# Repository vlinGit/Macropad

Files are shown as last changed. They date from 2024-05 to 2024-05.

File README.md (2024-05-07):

<h1 align="center"> Macropad </h1>

## Table of Contents
* [Introduction](#introduction)
* [Macropad](#macropad)
    * [Schematic](#schematic)
    * [PCB](#pcb)
    * [Parts](#parts)
* [Firmware](#firmware)
    * [Default mode](#default-mode)
    * [Function mode](#function-mode)
* [Future plans](#future-plans)

<hr>

## Introduction

Greetings, It seems you've stubbled upon my macropad project :)!
Utilizing everything provided from this repo (with a few exceptions) you should be able to make this simple 4x4 macropad using a Pi Pico:

<p align="center">
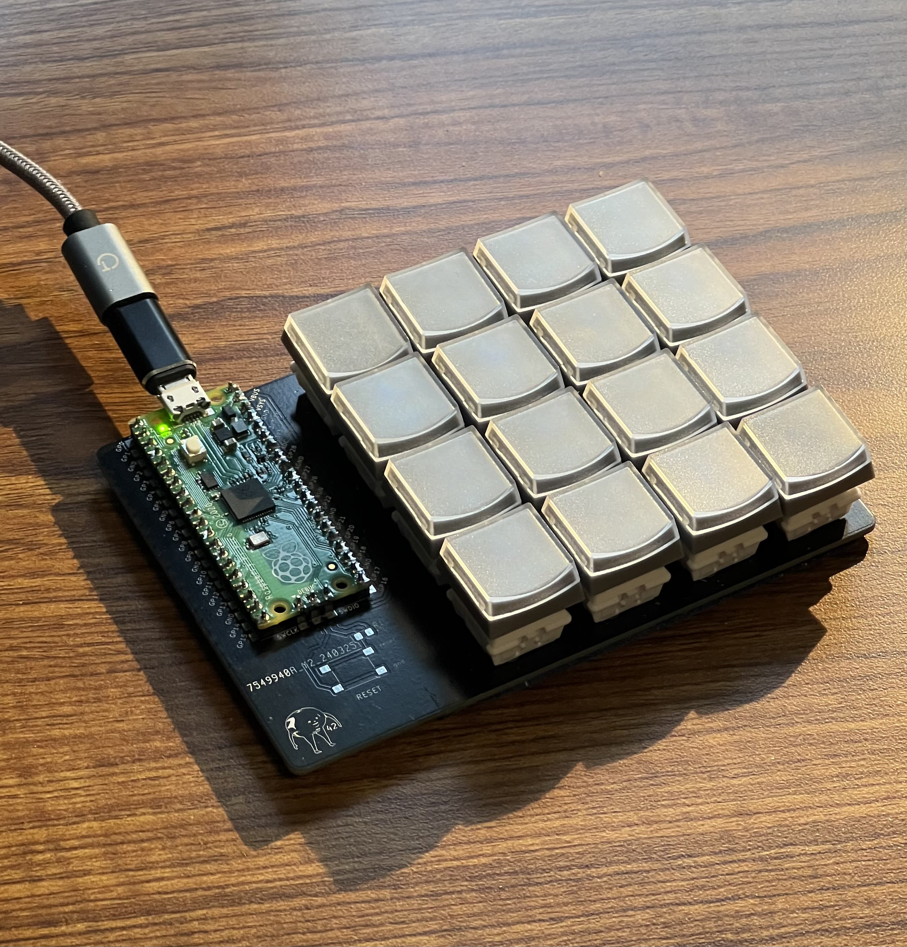
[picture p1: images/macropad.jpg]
    
</p>

Now I must set some ground rules and mentions those exceptions from the previous text. 
This repo assumes you have knowledge of:

* [Python](https://www.python.org/)
* [Kicad](https://www.kicad.org/)
* [CircuitPython](https://circuitpython.org/) - This should be installed on your Pi Pico

The next two sections will discuss what the two folders, Macropad and Firmware, in this project do.
<hr>

## Macropad

All the project files (schematic, pcb, and fingerprints) should be in this folder. When opening this within Kicad, you will most likely need to reassign the location of the fingerprints.

##### Schematic:
<p align="center">
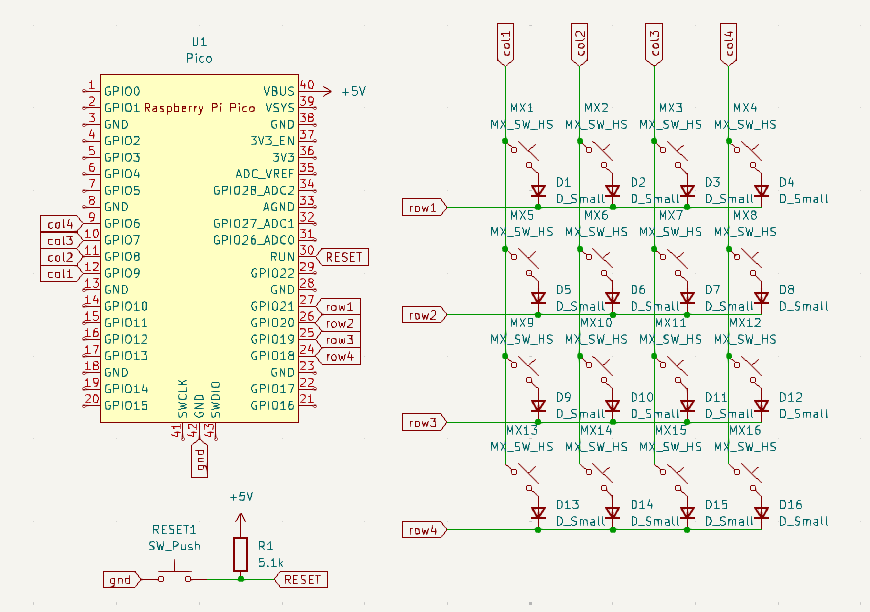
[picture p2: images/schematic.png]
    
</p>

##### PCB:
<p align="center">
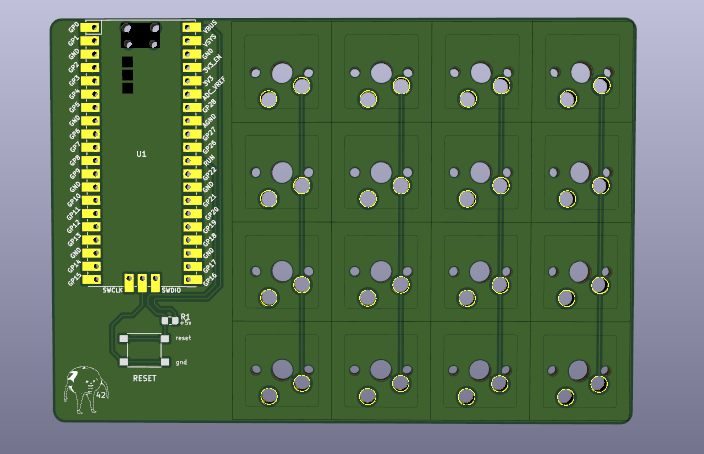
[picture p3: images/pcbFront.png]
    
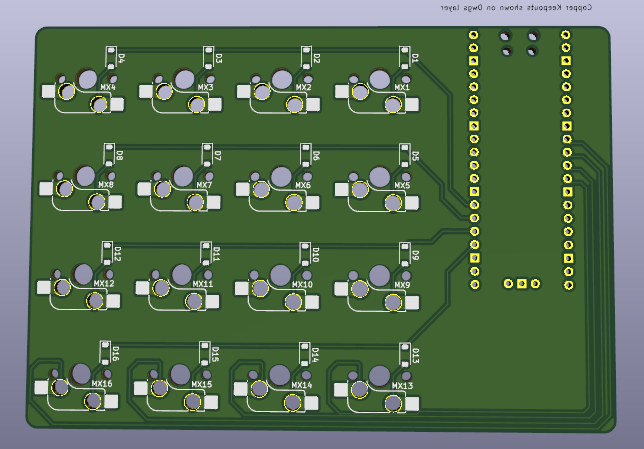
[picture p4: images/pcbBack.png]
    
</p>

##### Parts:
* 16 Kahlil hotswap sockets
* 1 Raspberry Pi Pico
* 16 SMD Diodes
* Header pins for the pico (optional)
* Micro usb wire
* Soldering kit

Here's a [spreadsheet](https://docs.google.com/spreadsheets/d/1NUBolih80QTXxrNlfvGj-lknc-THMJnu64dy0pHb7lM/edit?usp=sharing) containing all the items I used. This spreadsheet doesn't include headers, switches, and keys as I already had these lying around.

<i><b>Sidenote</b>, I left a place for a reset button for convinence, however, this proved to be the complete opposite. The small button got in the way more often than not so the final build doesn't include it. </i>

<hr>

## Firmware

You will find a <b>lib</b> folder as well as a <b>code.py</b> file in here. The <b>lib</b> folder contains the necessary adafruit library needed for the python file <b>code.py</b> which contains the actual firmware code. These files should be dragged into your Pi Pico after you've installed CircuitPython.

The macropad is designed in a 4x4 matrix with the following pins:

* Rows: GP21, GP20, GP19, GP18
* Columns: GP6, GP7, GP8, GP9

The current python file provides you with two modes:
1. [Default mode](#default-mode) - for media controls
2. [Function mode](#function-mode) - for general purpose binds using F13-F21 keys, mainly for binding macros in software (blender, kritia, etc.)

The modes will be presented in tables, each cell being a key. Every cell labeled <i>null</i> means the key is unassigned. Within the actual code this is represented with a -1.

##### Default Mode:

<table>
    <tr>
        <td>VOLUME DECREMENT</td>
        <td>VOLUME INCREMENT</td>
        <td>MUTE VOLUME</td>
        <td>CHANGE MODE</td>
    </tr>
    <tr>
        <td>PREVIOUS TRACK</td>
        <td>PLAY/PAUSE MEDIA</td>
        <td>NEXT TRACK</td>
        <td><i>null</i></td>
    </tr>
    <tr>
        <td><i>null</i></td>
        <td><i>null</i></td>
        <td><i>null</i></td>
        <td><i>null</i></td>
    </tr>
    <tr>
        <td><i>null</i></td>
        <td><i>null</i></td>
        <td><i>null</i></td>
        <td><i>null</i></td>
    </tr>
</table>

##### Function Mode:

<table>
    <tr>
        <td>LEFT SHIFT</td>
        <td>F14</td>
        <td>F15</td>
        <td>CHANGE MODE</td>
    </tr>
    <tr>
        <td>F13</td>
        <td>F17</td>
        <td>F18</td>
        <td>F19</td>
    </tr>
    <tr>
        <td>F16</td>
        <td>F21</td>
        <td>F22</td>
        <td>F23</td>
    </tr>
    <tr>
        <td>LEFT CONTROL</td>
        <td>F20</td>
        <td><i>null</i></td>
        <td>SPACE</td>
    </tr>
</table>

<hr>

## Future plans

So, whats planned for the future? I've been using this macropad for a couple days now and here's the following things I plan on implementing soon:

1. <b>Proper case</b> - I've created the model, but now just need to get a 3D printer and do some troubleshooting
2. <b>Rotary Encoders</b> - Will be great for volume control and zooming in
3. <b>Standalone LED + Mode button</b> - Just for mode switching
4. <b>IR Sensors</b> - Really looking forward to this one! Plan on adding AC and table height controls using this.

As to what I will remove:
1. <b>The reset button</b> - Honestly made it less comfortable to use
2. <b>Micro usb</b>- Looking to replace this with a USB-C port

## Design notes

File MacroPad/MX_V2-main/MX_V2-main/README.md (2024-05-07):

Cover Image 
# MX_V2
Second generation KiCad Libraries of keyboard switch footprints  

<!-- ![Footprint Image](https://raw.githubusercontent.com/ai03-2725/MX_Alps_Hybrid.pretty/master/Screenshots/Footprint.png)   -->
Designed as the successor to [the original MX_Alps_Hybrid library](https://github.com/ai03-2725/MX_Alps_Hybrid), with significantly improved sustainability and modularity.  
Unlike the original monolithic library, this new library separates switch types and components (LEDs and similar) as much as possible for simpler schematics, and is intended to be used with default KiCad symbols (such as `SW_Push`).

## Features
* Designed from scratch using official datasheets and accurate measurements
* Almost every switch size in existence
* Topside soldermask to prevent solder overflow and improve appearance
* Various keysizes for all occasions
* Keysizes are generated via the script generate.py from a single footprint, making the library extensible and maintainable
* Intended for production use

## Included Footprint Libraries
* **MX_Solderable.pretty** - For Cherry MX type switches via soldered pads.
* **MX_Hotswap.pretty** - For Cherry MX type switches via hotswap sockets.
* **Alps_Solderable.pretty** - For alps SKCM/SKCL, SKBM/SKBL, and clones with same pin structure.  
* **MX_Alps_Hybrid.pretty** - Hybrid MX/Alps compatible solderable footprints.
* **Gateron_KS33_Solderable.pretty** - For Gateron Low Profile (V1.0 or V2.0, KS-27 or KS-33) switches via soldered pads.
* **Gateron_KS33_Hotswap.pretty** - For Gateron Low Profile (V1.0 or V2.0, KS-27 or KS-33) switches via hotswap sockets.
* **Switch_Misc.pretty** - Misc footprints such as LED footprints.
* Template.pretty - The template footprints that the script uses to generate footprints automatically. Do not use in production.

### Footprint Variants
* -ReversedStabilizers - Reversed stabilizer direction (north- vs south-facing).

### Misc Parts Variants
* -LED - LEDs that align to each switch footprint. Prefix denotes which type of switch they are applicable to.
* -Reversed - Inverts pin 1 order (left vs right square pad).
* -PolarityMarked - Marks pin 1 with a + icon to denote positive polarity (only useful if pin 1 is the higher voltage).

### 3D Model Troubleshooting
Due to limitations in KiCad, there is no particularly elegant way to handle 3D models for non-plugin third-party libraries.  
If you have issues seeing the 3D models or exporting them in STEP files, copy the contents of the `3D` directory to your project's root folder alongside the kicad project files.  

## Contributing
Verbal "Please create this" will usually be declined due to lack of time available for maintenance.  
Massive overhauls that completely change the structure of the library or code will be declined if made without prior discussion.  
When creating PRs, please verify the following:  
* A template footprint is created in Template.pretty if creating a new family type, with the file modified to have "Template" for all script-replaced unit/variant text.  
* Code modifications are done in a sane, clean manner.
* Footprints are made from datasheets, empirical testing, and/or reasonable expectations.
* All footprints in a switch library (i.e. not a one-off LED footprint or similar) are generated from the script and are not manually modified.
* Once everything is tested functional, add the line to generate the library folder for the footprint family automatically in `Generator/generate-all.sh`.

### Todo
* Script todos
  * Make ISO outlines scale by unit width/height parameters
  * Add stabilizer clearance keepout zones for Gateron KS33 footprints
* Ease of use
  * Add screenshots of 3D model, footprint

## Credits
* All authors and contributors to the [original V1 switch library](https://github.com/ai03-2725/MX_Alps_Hybrid)

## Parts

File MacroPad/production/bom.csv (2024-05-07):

Designator | Footprint | Quantity | Value | LCSC Part #
D1, D10, D11, D12, D13, D14, D15, D16, D2, D3, D4, D5, D6, D7, D8, D9 | D_SOD-123 | 16 | D_Small
MX1, MX10, MX11, MX12, MX13, MX14, MX15, MX16, MX2, MX3, MX4, MX5, MX6, MX7, MX8, MX9 | SW_MX_HS_CPG151101S11_1u | 16 | MX_SW_HS
R1 | 0805 | 1 | 5.1k
RESET | SW_SPST_PTS645 | 1 | SW_Push
U1 | RPi_Pico_SMD_TH | 1 | Pico

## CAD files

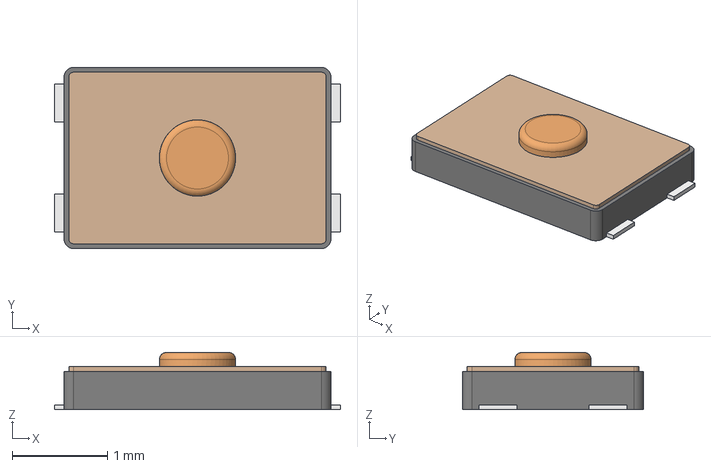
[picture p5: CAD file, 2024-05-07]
MacroPad/marbastlib-main/marbastlib-main/3dmodels/SW_T1A2QR.step
3.00 x 1.90 x 0.6 mm

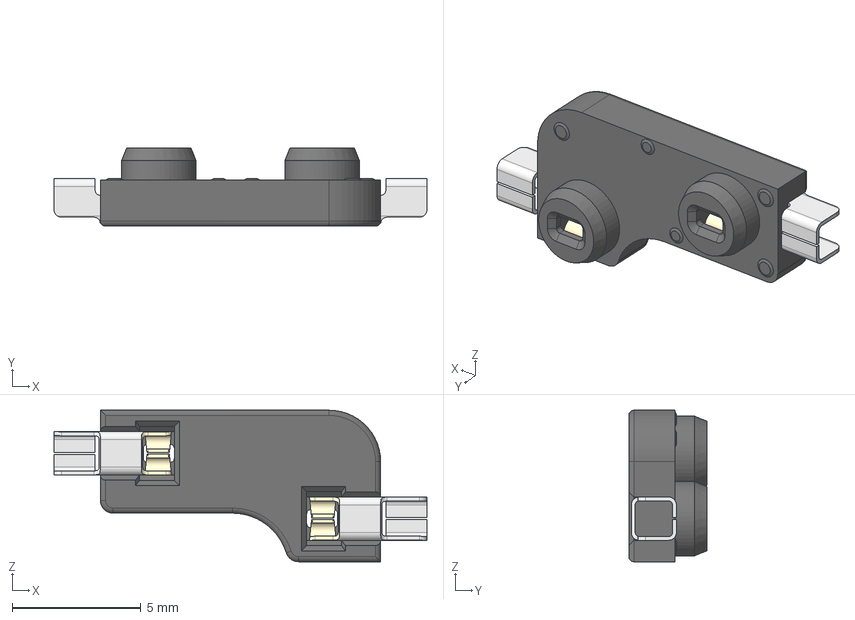
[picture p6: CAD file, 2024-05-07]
MacroPad/MX_V2-main/MX_V2-main/3D/MX-Hotswap-Socket.step
14.5 x 3.05 x 5.89 mm

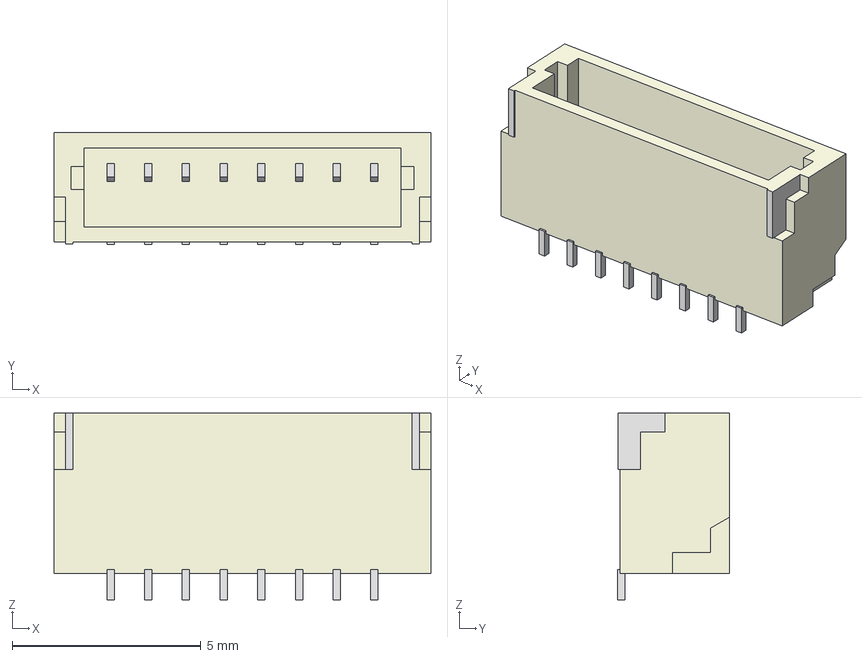
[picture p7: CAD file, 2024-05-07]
MacroPad/marbastlib-main/marbastlib-main/3dmodels/CON_SM08B-SRSS-TB.step
10.0 x 2.96 x 4.95 mm

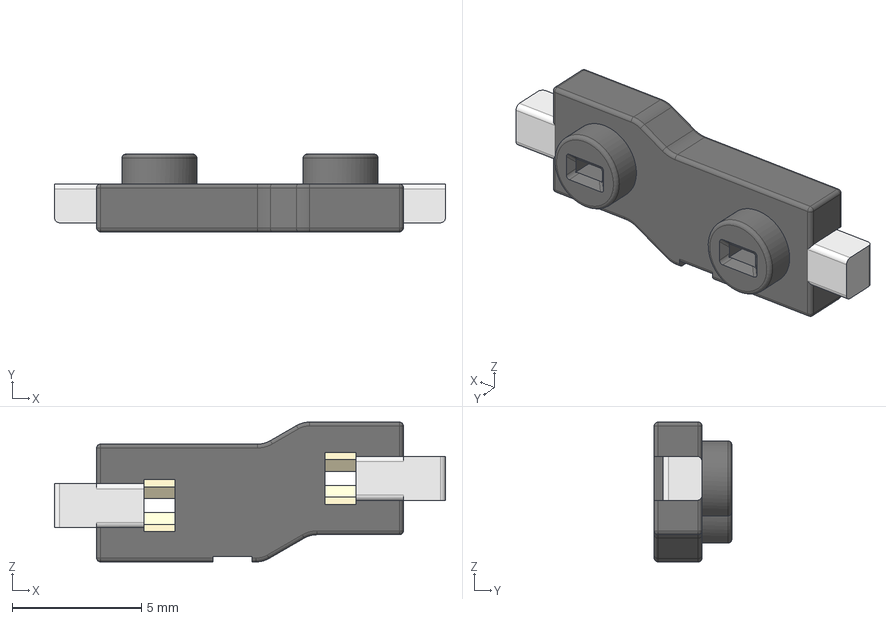
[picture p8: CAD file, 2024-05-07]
MacroPad/MX_V2-main/MX_V2-main/3D/Gateron-KS33-Socket.step
15.1 x 3.00 x 5.40 mm

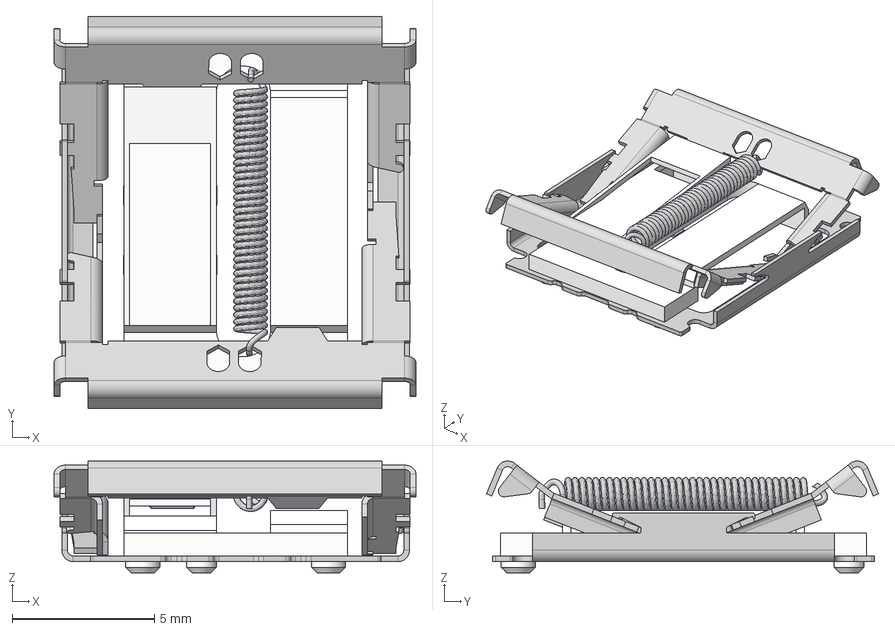
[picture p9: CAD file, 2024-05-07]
MacroPad/marbastlib-main/marbastlib-main/3dmodels/SW_MX6C-K3NB.step
12.7 x 13.8 x 3.93 mm

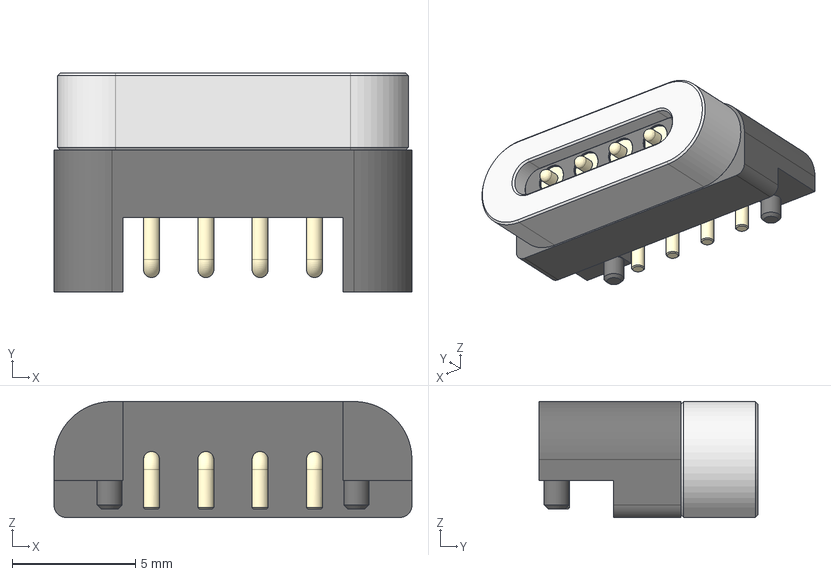
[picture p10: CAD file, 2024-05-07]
MacroPad/marbastlib-main/marbastlib-main/3dmodels/CON_HytePro_M411P_Receptacle_1x04.step
14.5 x 8.85 x 4.70 mm
Magnetic Connector Female - MiddlePart
Magnetic Connector Female-tip_Standard
Magnetic Connector Female v2 - MountingPart

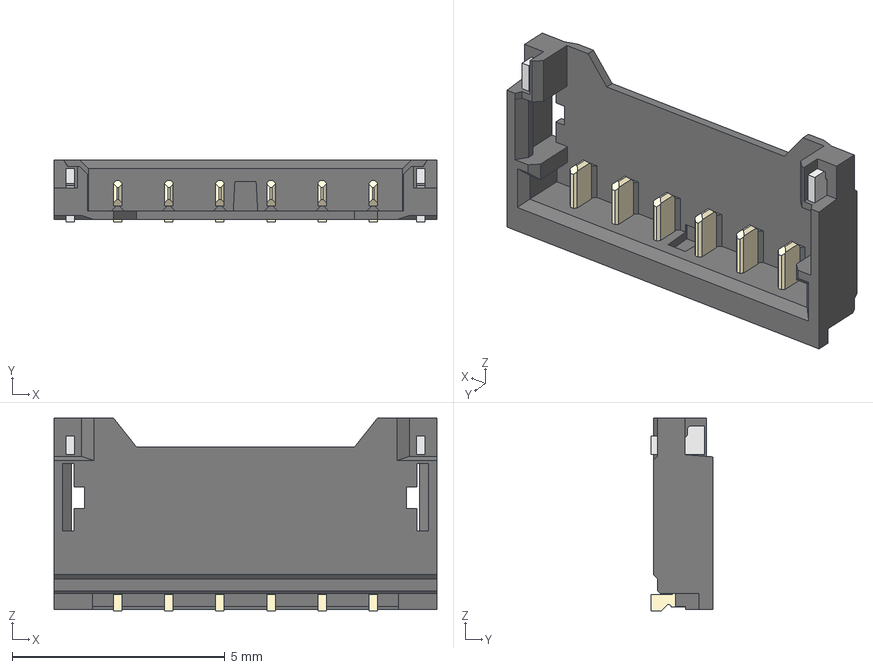
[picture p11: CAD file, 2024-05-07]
MacroPad/marbastlib-main/marbastlib-main/3dmodels/CON_781715006.step
9.00 x 1.45 x 4.53 mm

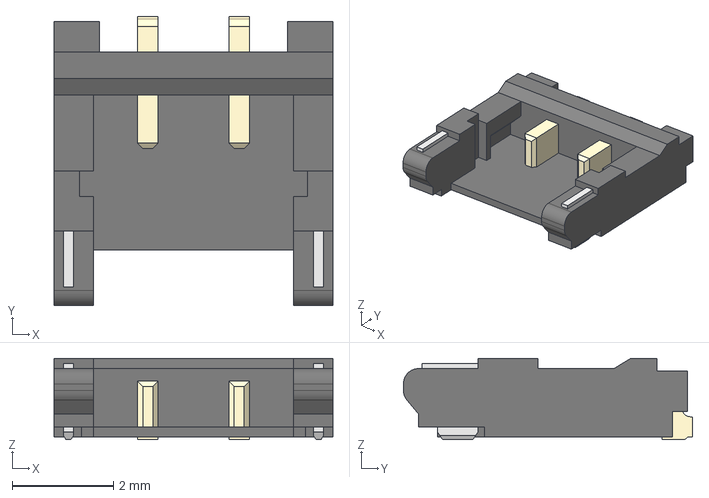
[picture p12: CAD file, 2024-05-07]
MacroPad/marbastlib-main/marbastlib-main/3dmodels/CON_2082940020.step
5.50 x 5.70 x 1.60 mm

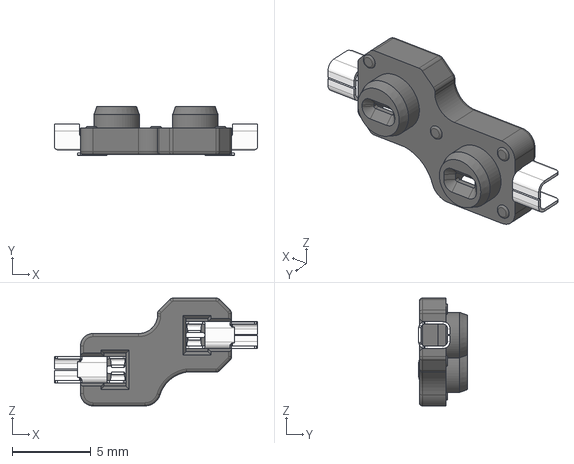
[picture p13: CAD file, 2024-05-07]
MacroPad/marbastlib-main/marbastlib-main/3dmodels/HS_CPG135001S30_Choc.step
12.9 x 3.09 x 6.85 mm
pin x 2
socket

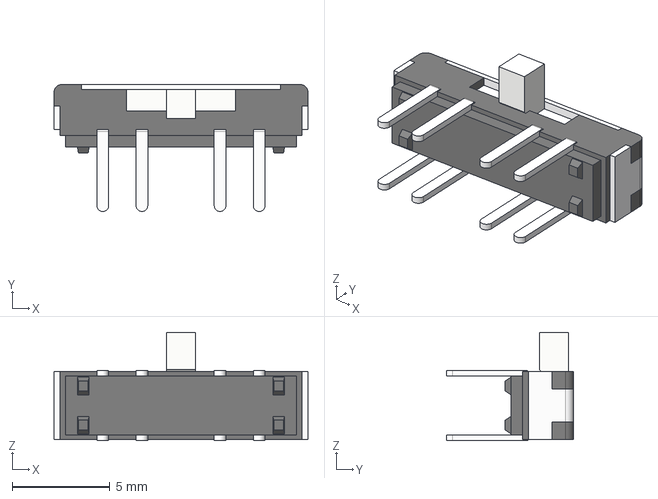
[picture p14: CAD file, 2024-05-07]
MacroPad/marbastlib-main/marbastlib-main/3dmodels/SW_SSSS223900.step
13.0 x 6.50 x 5.55 mm

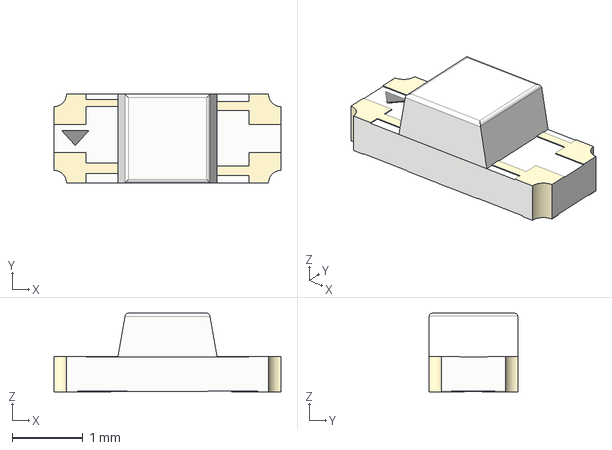
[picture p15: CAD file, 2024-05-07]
MacroPad/marbastlib-main/marbastlib-main/3dmodels/LED_MHT151RGBCT.step
3.20 x 1.25 x 1.11 mm

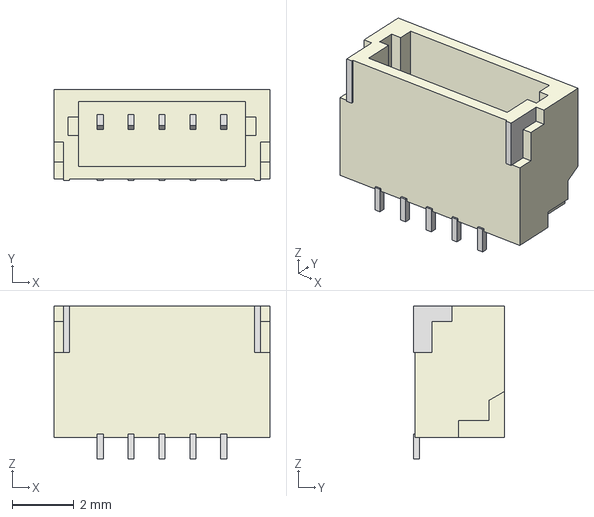
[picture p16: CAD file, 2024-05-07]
MacroPad/marbastlib-main/marbastlib-main/3dmodels/CON_SM05B-SRSS-TB.step
7.00 x 2.96 x 4.95 mm

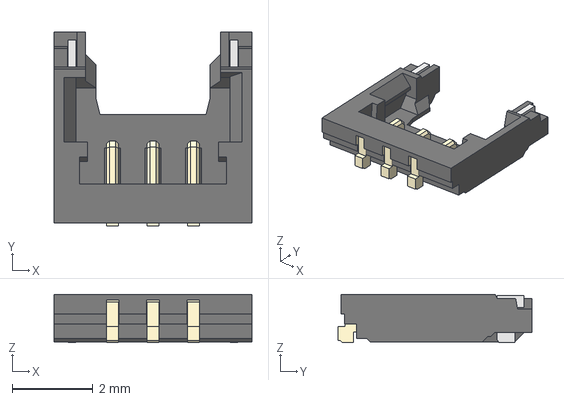
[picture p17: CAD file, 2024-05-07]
MacroPad/marbastlib-main/marbastlib-main/3dmodels/CON_2121340003.step
4.90 x 4.79 x 1.20 mm

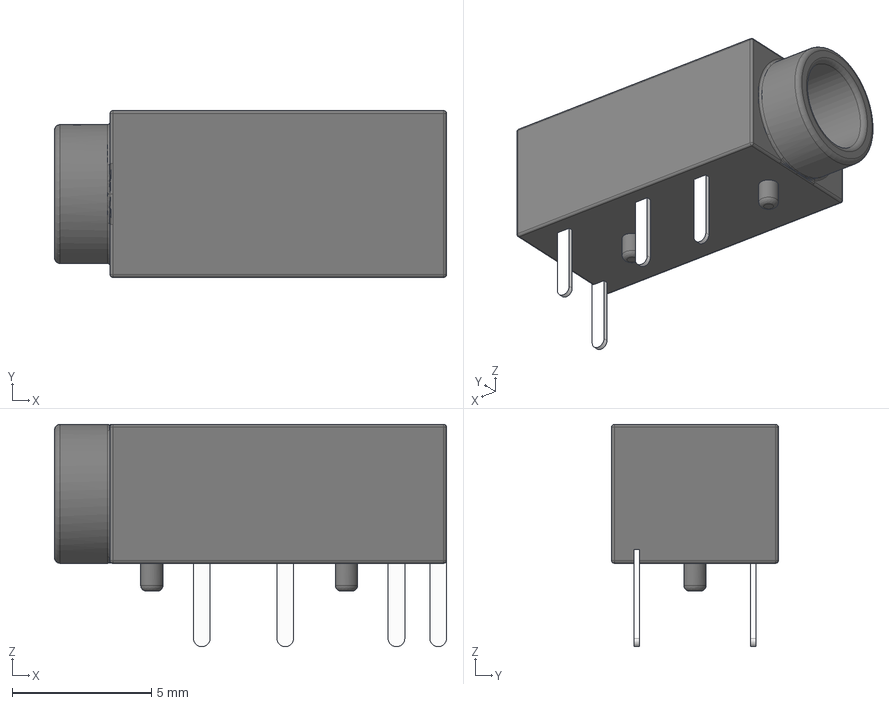
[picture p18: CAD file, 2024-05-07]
MacroPad/marbastlib-main/marbastlib-main/3dmodels/CON_MJ-4PP-9.step
14.1 x 6.00 x 8.00 mm

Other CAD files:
MacroPad/marbastlib-main/marbastlib-main/3dmodels/SW_SKHLLC.step
MacroPad/marbastlib-main/marbastlib-main/3dmodels/SW_SSSS213100.step
MacroPad/marbastlib-main/marbastlib-main/3dmodels/PNT_psp1000.step
MacroPad/marbastlib-main/marbastlib-main/3dmodels/SW_MSK12C02.step
MacroPad/KiCad-RP-Pico-main/KiCad-RP-Pico-main/SketchUp Model/Pico.skp
MacroPad/marbastlib-main/marbastlib-main/3dmodels/CON_2082940030.step
MacroPad/marbastlib-main/marbastlib-main/3dmodels/CON_2082940040.step
MacroPad/marbastlib-main/marbastlib-main/3dmodels/CON_2082940050.step
MacroPad/marbastlib-main/marbastlib-main/3dmodels/CON_2121340002.step
MacroPad/marbastlib-main/marbastlib-main/3dmodels/CON_2121340004.step
MacroPad/marbastlib-main/marbastlib-main/3dmodels/CON_2121340005.step
MacroPad/marbastlib-main/marbastlib-main/3dmodels/CON_2121340006.step
MacroPad/marbastlib-main/marbastlib-main/3dmodels/CON_781710002.step
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

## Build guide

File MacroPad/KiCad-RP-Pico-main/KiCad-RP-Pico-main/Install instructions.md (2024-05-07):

# Install instructions

## 1. Copy the files locally

Copy the `RP-Pico Libraries` folder wherever you like on your computer.

## 2. Install the Raspberry Pi Pico board schema symbol

Use the `KiCad | Preferences | Manage Symbol Libraries...` command to manage the symbol library:



then select the global tab and click on the folder button:



navigate to the `RP-Pico Libraries` folder, select the `MCU_RaspberryPi_and_Boards.kicad_sym` file and open it:



et voilà, the first step is completed:



You can now close the symbol libraries manager window.

## 3. Install the Raspberry Pi Pico board footprint

You can use a similar approach to add the footprint to the footprint libraries manager, but I've found some issues that I've solved using the footprint editor, so here are the steps I suggest you to follow:

Open the footprint editor



wait for the footprints to load... then use the `File | Add Library` command:



confirm the `Global` choice:



and select the `MCU_RaspberriPi_and_Boards.pretty` folder (yes, the folder represent a footprint library on KiCad):



Now the library is installed on KiCad with the Raspberry Pi Pico footprint (double click on it to see it on the editor pane):



Don't close the windows as the next step start from here.

## 4. Install the Raspberry Pi Pico board footprint 3D visual

If not already open, open the the footprint editor

symbol library manager

double click on the `RPi_Pico_SMD_TH` footprint from the `MCU_RaspberriPi_and_Boards` library and then click on the `Footprint properties` icon:



In the footprint properties window, first select the `3D Settings` tab. Please note that the preview shows only the PCB board with the footprint added on step 3, without any 3D representation of the Raspberry Pi Pico board. Now click on the folder icon to add the 3D model:



Navigate to the `RP-Pico Libraries` folder, select the `Pico.wrl` file and wait until the model is shown in the right panel, then confirm with OK:



The model is already scaled and translated to match the footprint:



now close the `Footprint Properties` window, and the `Footprint Editor`, obviously saving the changes.

## Conclusion

Now that you've installed the schema and footprint and added the 3D model to the footprint, you can use the Raspberry Pi Pico board on your KiCad projects.

I've also added a test KiCad Project on the `Test` folder, that you can use to see an example of it.

Have fun!

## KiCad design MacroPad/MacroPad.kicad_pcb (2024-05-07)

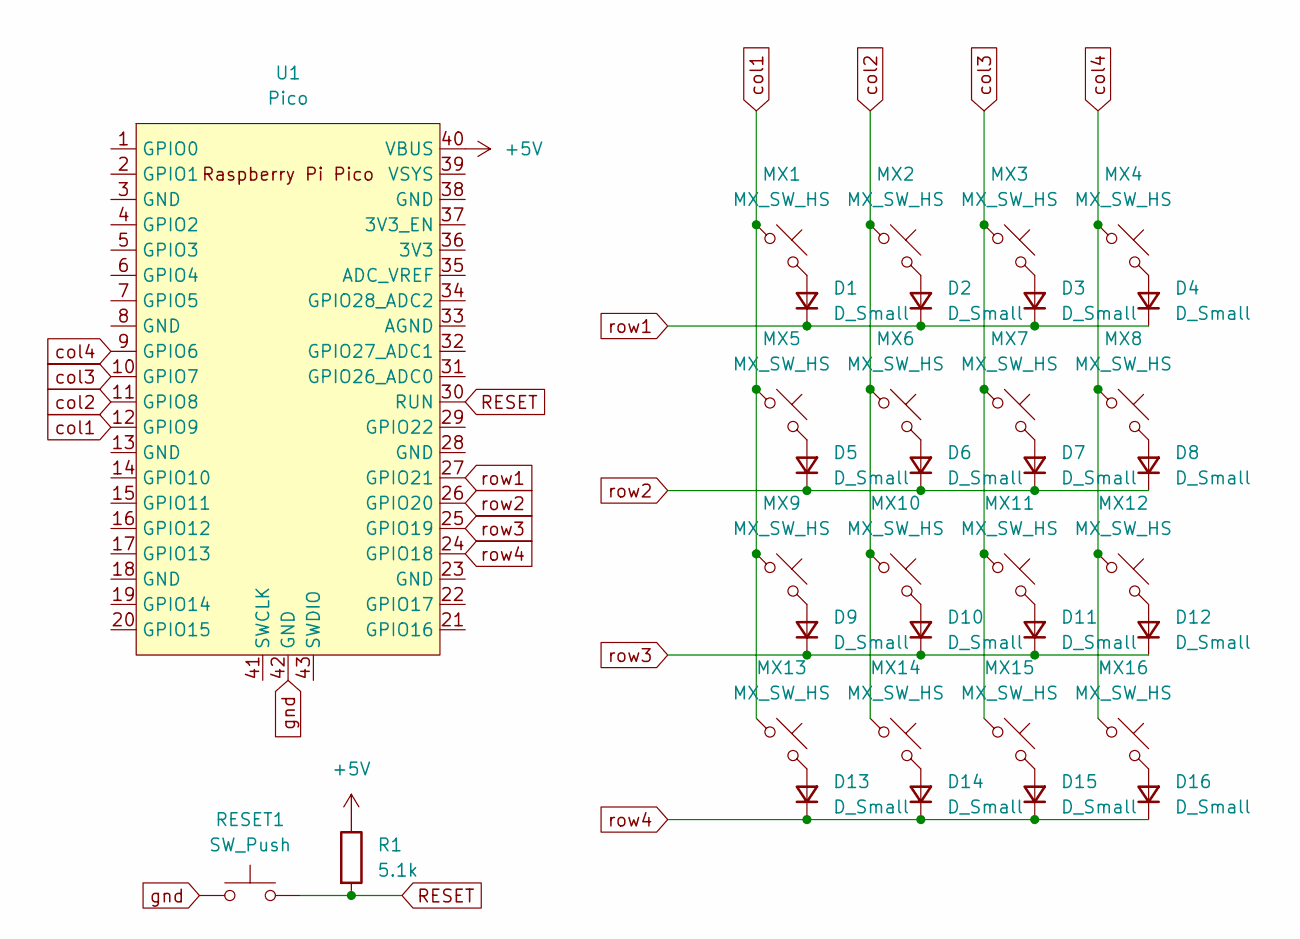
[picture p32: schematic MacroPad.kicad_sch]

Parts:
D1, D2, D3, D4, D5, D6, D7, D8, D9, D10, D11, D12, D13, D14, D15, D16: D_Small; D_SOD-123
MX1, MX2, MX3, MX4, MX5, MX6, MX7, MX8, MX9, MX10, MX11, MX12, MX13, MX14, MX15, MX16: MX_SW_HS; SW_MX_HS_CPG151101S11_1u
R1: 5.1k; R_0805_2012Metric_Pad1.20x1.40mm_HandSolder
RESET1: SW_Push; SW_SPST_PTS645
U1: Pico; RPi_Pico_SMD_TH

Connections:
+5V: R1.1, U1.40 (VBUS)
unnamed: D1.2 (A), MX1.2
unnamed: D2.2 (A), MX2.2
unnamed: D3.2 (A), MX3.2
unnamed: D4.2 (A), MX4.2
unnamed: D5.2 (A), MX5.2
unnamed: D6.2 (A), MX6.2
unnamed: D7.2 (A), MX7.2
unnamed: D8.2 (A), MX8.2
unnamed: D9.2 (A), MX9.2
unnamed: D10.2 (A), MX10.2
unnamed: D11.2 (A), MX11.2
unnamed: D12.2 (A), MX12.2
unnamed: D13.2 (A), MX13.2
unnamed: D14.2 (A), MX14.2
unnamed: D15.2 (A), MX15.2
unnamed: D16.2 (A), MX16.2
RESET: R1.2, RESET1.2, U1.30 (RUN); also elsewhere on the board
col1: MX1.1, MX5.1, MX9.1, MX13.1, U1.12 (GPIO9)
col2: MX2.1, MX6.1, MX10.1, MX14.1, U1.11 (GPIO8)
col3: MX3.1, MX7.1, MX11.1, MX15.1, U1.10 (GPIO7)
col4: MX4.1, MX8.1, MX12.1, MX16.1, U1.9 (GPIO6)
gnd: RESET1.1, U1.42 (GND); also elsewhere on the board
row1: D1.1 (K), D2.1 (K), D3.1 (K), D4.1 (K), U1.27 (GPIO21)
row2: D5.1 (K), D6.1 (K), D7.1 (K), D8.1 (K), U1.26 (GPIO20)
row3: D9.1 (K), D10.1 (K), D11.1 (K), D12.1 (K), U1.25 (GPIO19)
row4: D13.1 (K), D14.1 (K), D15.1 (K), D16.1 (K), U1.24 (GPIO18)

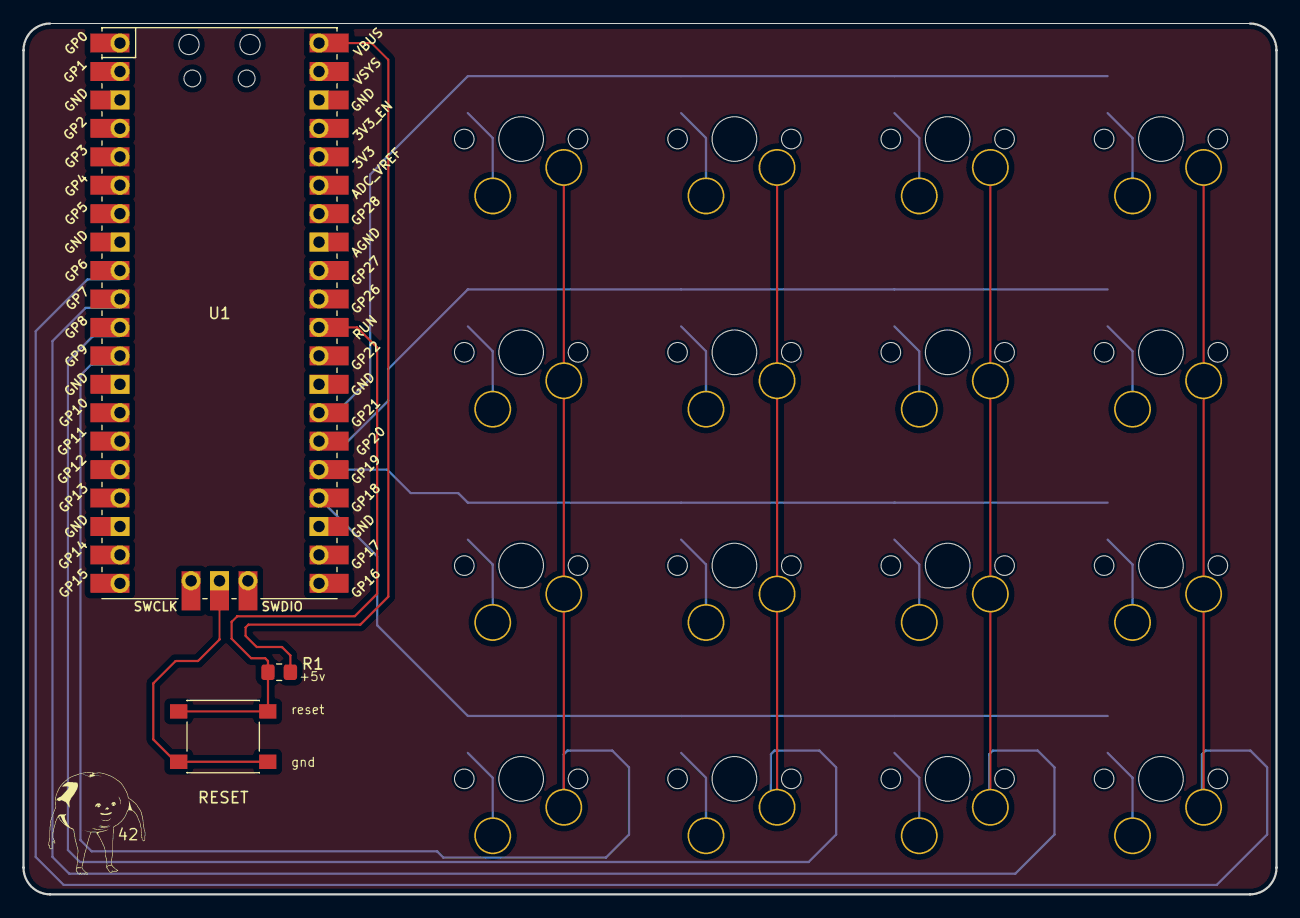
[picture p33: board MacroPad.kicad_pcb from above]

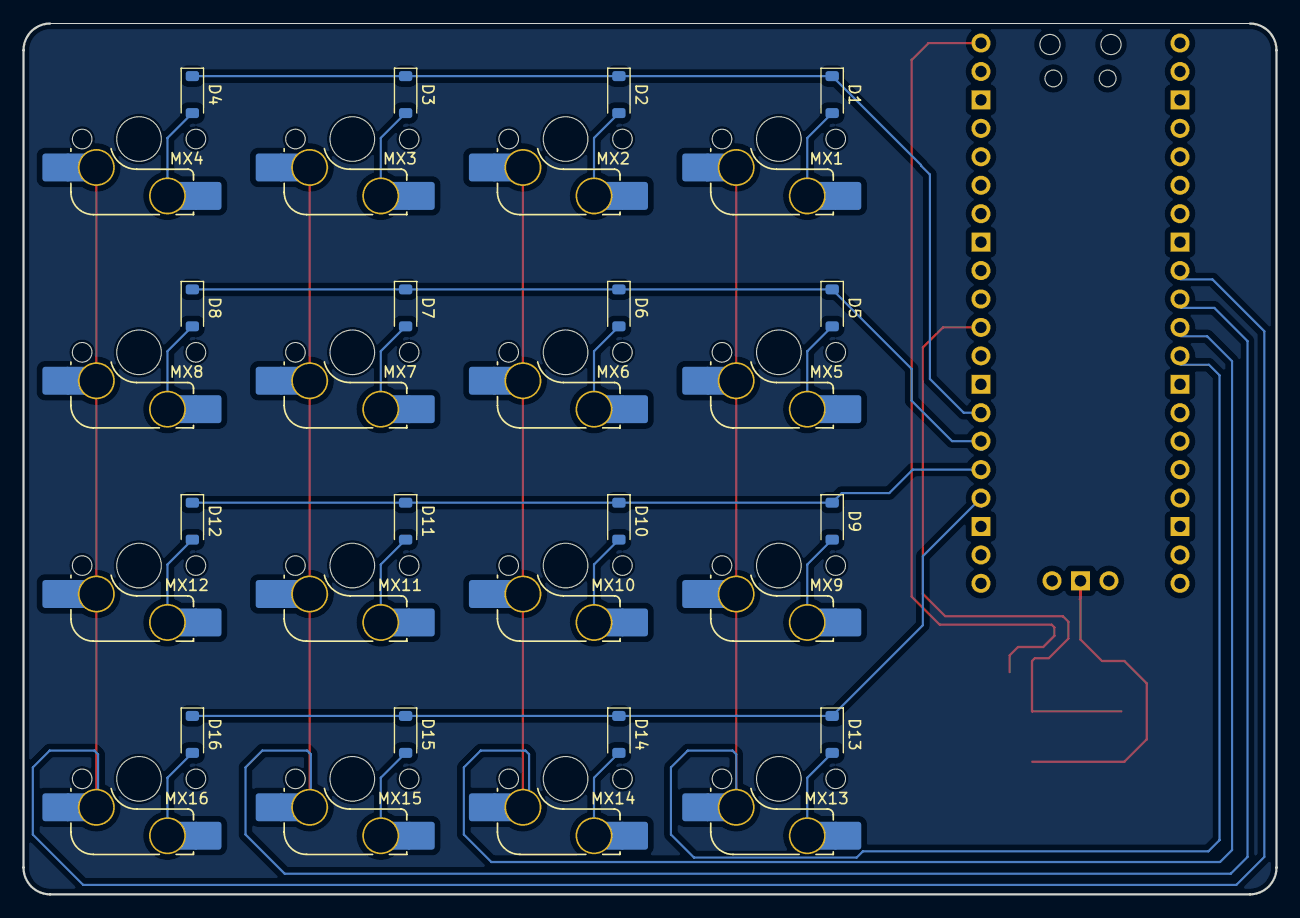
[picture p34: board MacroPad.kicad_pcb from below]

Board: 2 copper layers, 111.9 x 77.8 mm, 36 parts (32 on the bottom side), 27 nets.

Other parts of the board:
42: LOGO
RESET: SW_Push; SW_SPST_PTS645

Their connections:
RESET: RESET.2; also elsewhere on the board
gnd: RESET.1; also elsewhere on the board

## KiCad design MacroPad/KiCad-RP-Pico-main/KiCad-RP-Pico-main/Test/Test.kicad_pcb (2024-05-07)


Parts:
J1, J2: Conn_01x20; PinSocket_1x20_P1.00mm_Vertical
J3: Conn_01x03; PinSocket_1x03_P1.00mm_Vertical
U1: Pico; RPi_Pico_SMD_TH

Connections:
GND: J1.3, J1.8, J1.13, J1.18, J2.3, J2.13, J2.18, J3.2, U1.3 (GND), U1.8 (GND), U1.13 (GND), U1.18 (GND), U1.23 (GND), U1.28 (GND), U1.38 (GND), U1.42 (GND)
unnamed: J1.1, U1.1 (GPIO0)
unnamed: J1.2, U1.2 (GPIO1)
unnamed: J1.4, U1.4 (GPIO2)
unnamed: J1.5, U1.5 (GPIO3)
unnamed: J1.6, U1.6 (GPIO4)
unnamed: J1.7, U1.7 (GPIO5)
unnamed: J1.9, U1.9 (GPIO6)
unnamed: J1.10, U1.10 (GPIO7)
unnamed: J1.11, U1.11 (GPIO8)
unnamed: J1.12, U1.12 (GPIO9)
unnamed: J1.14, U1.14 (GPIO10)
unnamed: J1.15, U1.15 (GPIO11)
unnamed: J1.16, U1.16 (GPIO12)
unnamed: J1.17, U1.17 (GPIO13)
unnamed: J1.19, U1.19 (GPIO14)
unnamed: J1.20, U1.20 (GPIO15)
unnamed: J2.1, U1.40 (VBUS)
unnamed: J2.2, U1.39 (VSYS)
unnamed: J2.4, U1.37 (3V3_EN)
unnamed: J2.5, U1.36 (3V3)
unnamed: J2.6, U1.35 (ADC_VREF)
unnamed: J2.7, U1.34 (GPIO28_ADC2)
unnamed: J2.8, U1.33 (AGND)
unnamed: J2.9, U1.32 (GPIO27_ADC1)
unnamed: J2.10, U1.31 (GPIO26_ADC0)
unnamed: J2.11, U1.30 (RUN)
unnamed: J2.12, U1.29 (GPIO22)
unnamed: J2.14, U1.27 (GPIO21)
unnamed: J2.15, U1.26 (GPIO20)
unnamed: J2.16, U1.25 (GPIO19)
unnamed: J2.17, U1.24 (GPIO18)
unnamed: J2.19, U1.22 (GPIO17)
unnamed: J2.20, U1.21 (GPIO16)
unnamed: J3.1, U1.43 (SWDIO)
unnamed: J3.3, U1.41 (SWCLK)


Board: 2 copper layers, 43.0 x 65.0 mm, 4 parts (0 on the bottom side), 36 nets.

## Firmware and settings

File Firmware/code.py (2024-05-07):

import time
import board
import digitalio
import usb_hid
import keypad
from adafruit_hid.keyboard import Keyboard
from adafruit_hid.keycode import Keycode
from adafruit_hid.consumer_control import ConsumerControl
from adafruit_hid.consumer_control_code import ConsumerControlCode

kbd = Keyboard(usb_hid.devices)
cc = ConsumerControl(usb_hid.devices)
led = digitalio.DigitalInOut(board.LED)
led.switch_to_output()

rows = [board.GP21, board.GP20, board.GP19, board.GP18]  # Example pins, adjust as needed
columns = [board.GP9, board.GP8, board.GP7, board.GP6]  # Example pins, adjust as needed

# Keymap definition as well as different modes
mediaMode = [
    ConsumerControlCode.VOLUME_DECREMENT , ConsumerControlCode.VOLUME_INCREMENT, ConsumerControlCode.MUTE, 3,
    ConsumerControlCode.SCAN_PREVIOUS_TRACK , ConsumerControlCode.PLAY_PAUSE, ConsumerControlCode.SCAN_NEXT_TRACK , -1,
    -1, -1, -1, -1,
    -1, -1, -1 , -1
]
functionMode = [
    Keycode.LEFT_SHIFT,Keycode.F14,Keycode.F15,"3",
    Keycode.F13,Keycode.F17,Keycode.F18,Keycode.F19,
    Keycode.F16,Keycode.F21,Keycode.F22,Keycode.F23,
    Keycode.LEFT_CONTROL, Keycode.F20, -1, Keycode.SPACE
]
reservedKeys = [3]
keys = mediaMode
currentMode = 0 # 0 = defaultMode, 1 = functionMode

km = keypad.KeyMatrix(
    row_pins = (board.GP21, board.GP20, board.GP19, board.GP18),
    column_pins = (board.GP9, board.GP8, board.GP7, board.GP6)
)

def getKey(keyNumber):
    if keyNumber < len(keys):
        return keys[keyNumber]
    return -1

def handleReservedKey(keyNumber):
    global currentMode, keys
    if keyNumber == 3:
        if currentMode:
            keys = mediaMode
            currentMode = 0
        else:
            keys = functionMode
            currentMode = 1

def handleKey(key):
    if currentMode == 0:
        cc.send(key)
    else:
        kbd.press(key)

def keyEvent(keyEvent):
    key = getKey(keyEvent.key_number)

    if key != -1:
        if keyEvent.pressed:
            if keyEvent.key_number in reservedKeys:
                handleReservedKey(keyEvent.key_number)
            else:
                handleKey(key)
        elif keyEvent.key_number not in reservedKeys:
            kbd.release(key)

    return key

def handleLed():
    if currentMode:
        led.value = True
    else:
        led.value = False

# Will be used in the future to remember the state of the pad mode after a reset
def writePadState(state):
    try:
        file = open("padState.txt", "w")
        file.truncate(0)
        file.write(state)
        file.close()
        return True
    except:
        return False

def getPadState():
    try:
        file = open("padState.txt", "r")
        state = file.readlines()[0]
        file.close()

        return state
    except:
        return ""

# Main loop
while True:
    event = km.events.get()

    handleLed()
    if event:
        key = keyEvent(event)

    time.sleep(0.001)  # Adjust delay as neede
